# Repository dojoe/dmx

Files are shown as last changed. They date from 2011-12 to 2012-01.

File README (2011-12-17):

Collection of my DMX512 related projects, mostly various
USB-DMX interfaces in varying levels of miniaturization.

interface/v1:
  My first Eagle-drawn DMX interface; all interfaces before
  it were made on breadboards. Features the famous FTDI FT232RL
  for USB-Serial conversion and a DS26C31 line driver.
  This is a "dumb" interface where the host needs to take
  care of the DMX protocol.

interface/v2:
  Still a dumb interface, but this one fits into a standard-
  issue XLR plug. Uses FT232RQ (same chip, smaller package)
  and a MAX485.

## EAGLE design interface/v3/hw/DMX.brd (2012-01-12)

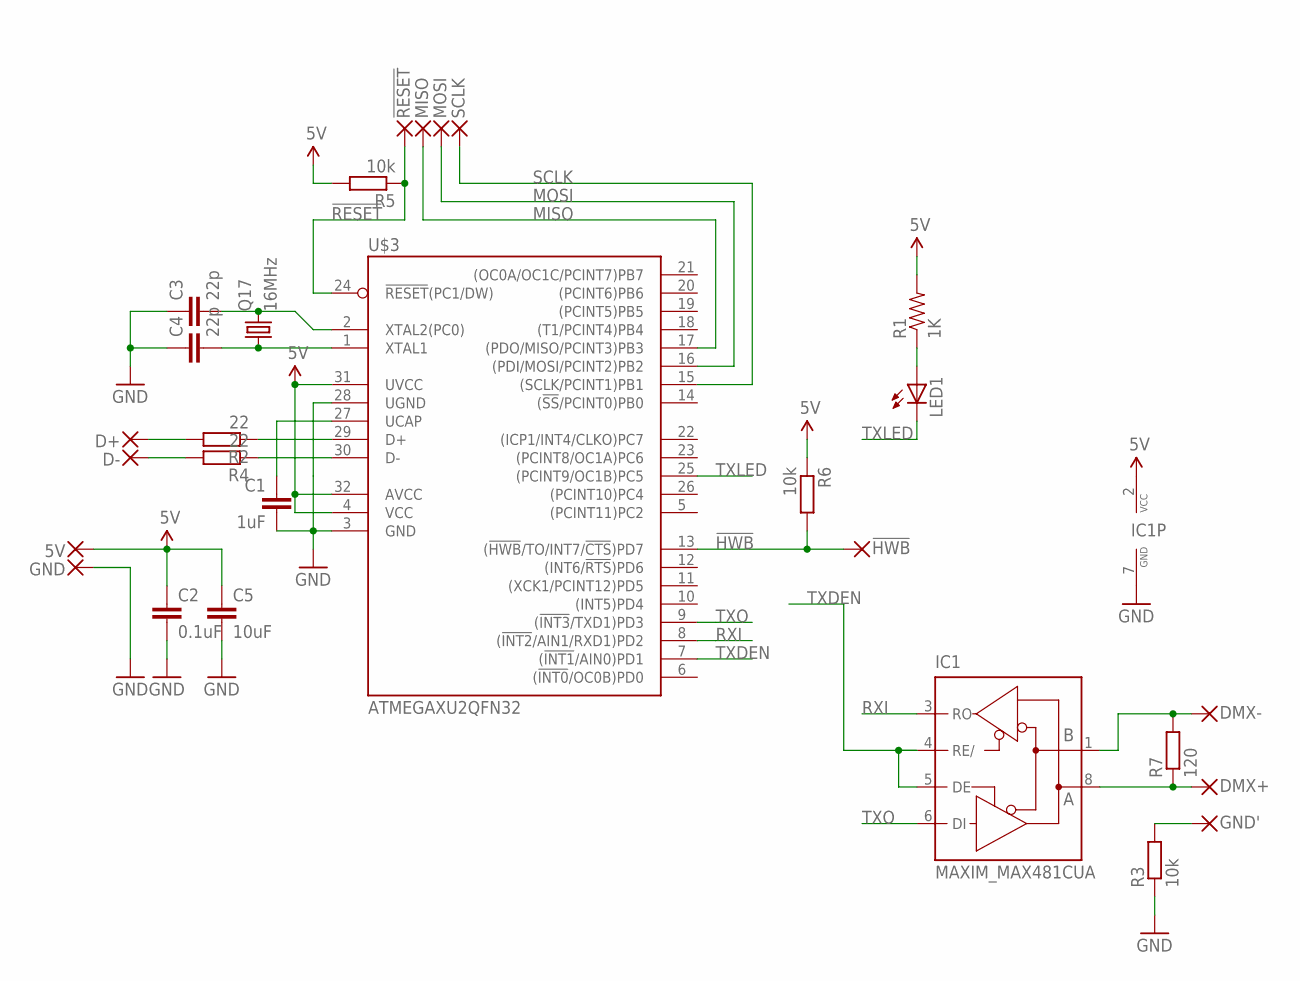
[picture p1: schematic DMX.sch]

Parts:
5V: WIREPAD2,15/1,0; 2,15/1,0
!HWB: WIREPADSMDCONTACT; SMDCONTACT
!RESET: WIREPADSMDCONTACT; SMDCONTACT
C1: 1uF; 0603-CAP
C2: 0.1uF; 0603-CAP
C3, C4: 22p; C0603
C5: 10uF; C0603K
D+: WIREPAD2,15/1,0; 2,15/1,0
D-: WIREPAD2,15/1,0; 2,15/1,0
DMX+: WIREPADSMD2,54-2,54; SMD2,54-2,54
DMX-: WIREPADSMD2,54-2,54; SMD2,54-2,54
GND: WIREPAD2,15/1,0; 2,15/1,0
GND': WIREPADSMD2,54-2,54; SMD2,54-2,54
IC1: MAXIM_MAX481CUA; MAXIM_UMAX8
LED1: LEDSML0805; SML0805
MISO: WIREPADSMDCONTACT; SMDCONTACT
MOSI: WIREPADSMDCONTACT; SMDCONTACT
Q17: 16MHz; TXC-7M
R1: 1K; 0603-RES
R2, R4: 22; R0603
R3, R5, R6: 10k; R0603
R7: 120; R0603
SCLK: WIREPADSMDCONTACT; SMDCONTACT
U$3: ATMEGAXU2QFN32; RHB_S-PQFP-N32

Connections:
5V: 5V.1, C2.1, C5.1, IC1.2 (VCC), R1.2, R5.2, R6.1, U$3.4 (VCC), U$3.31 (UVCC), U$3.32 (AVCC)
!HWB: !HWB.1, R6.2, U$3.13 ((!HWB!/TO/INT7/!CTS!)PD7)
!RESET: !RESET.1, R5.1, U$3.24 (!RESET!(PC1/DW))
DMX+: DMX+.1, IC1.8 (A), R7.1
DMX-: DMX-.1, IC1.1 (B), R7.2
GND: C1.2, C2.2, C3.1, C4.1, C5.2, GND.1, IC1.7 (GND), R3.1, U$3.3 (GND), U$3.28 (UGND)
GND': GND'.1, R3.2
MISO: MISO.1, U$3.17 ((PDO/MISO/PCINT3)PB3)
MOSI: MOSI.1, U$3.16 ((PDI/MOSI/PCINT2)PB2)
unnamed: LED1.A, R1.1
unnamed: C1.1, U$3.27 (UCAP)
unnamed: D+.1, R2.2
unnamed: D-.1, R4.2
unnamed: R2.1, U$3.29 (D+)
unnamed: R4.1, U$3.30 (D-)
unnamed: C3.2, Q17.B (2), U$3.2 (XTAL2(PC0))
unnamed: C4.2, Q17.A (1), U$3.1 (XTAL1)
RXI: IC1.3 (RO), U$3.8 ((!INT2!/AIN1/RXD1)PD2)
SCLK: SCLK.1, U$3.15 ((SCLK/PCINT1)PB1)
TXDEN: IC1.4 (RE/), IC1.5 (DE), U$3.7 ((!INT1!/AIN0)PD1)
TXLED: LED1.C, U$3.25 ((PCINT9/OC1B)PC5)
TXO: IC1.6 (DI), U$3.9 ((!INT3!/TXD1)PD3)

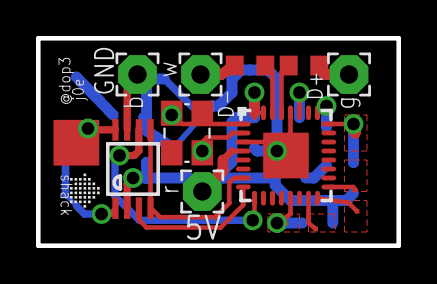
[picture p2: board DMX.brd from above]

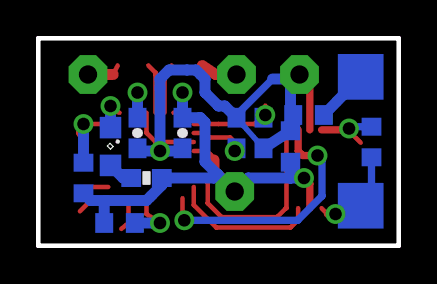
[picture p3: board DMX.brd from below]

Board: 2 copper layers, 20.0 x 11.5 mm, 28 parts (13 on the bottom side), 22 nets.
